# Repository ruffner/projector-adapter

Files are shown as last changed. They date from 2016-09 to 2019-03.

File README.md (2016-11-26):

# projector-adapter

ProjectorAdapter is a solution for timing camera exposure time with a Digital Micromirror Device (DMD) trigger signal for use in 3D recording.

The completed solution, show below, is connected to the projector with the bottom two cables, with the camera trigger cable out the top.
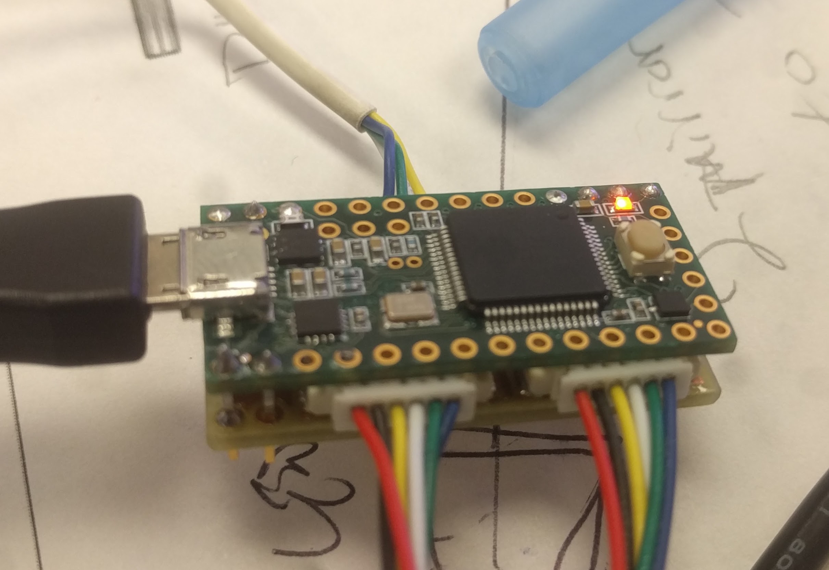
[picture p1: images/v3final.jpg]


### Hardware
The firmware runs on a [Teensy 3.2](https://www.pjrc.com/store/teensy32.html).

A custom made PCB was made with the same footprint as the Teensy3.2 with molex connectors for interfacing with a camera and projector DMD.

The PCB sits below the Teensy, with the 6 pin connectors to and from the projector and the 4 pin header routed to the camera trigger cable.

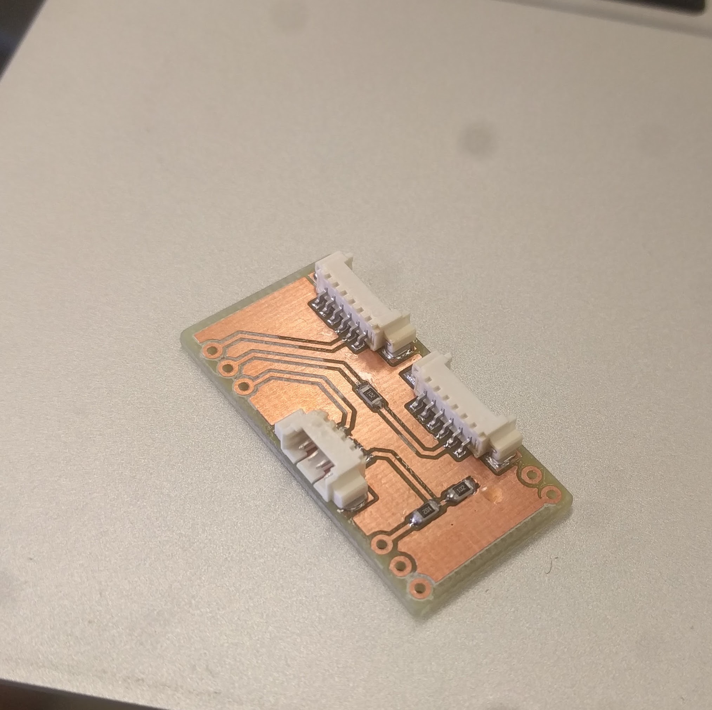
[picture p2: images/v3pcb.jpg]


It is written to interface with Ximea cameras using [this](https://www.ximea.com/support/wiki/apis/XiAPI_Camera_Trigger_and_Synchronization_Signals) protocall.

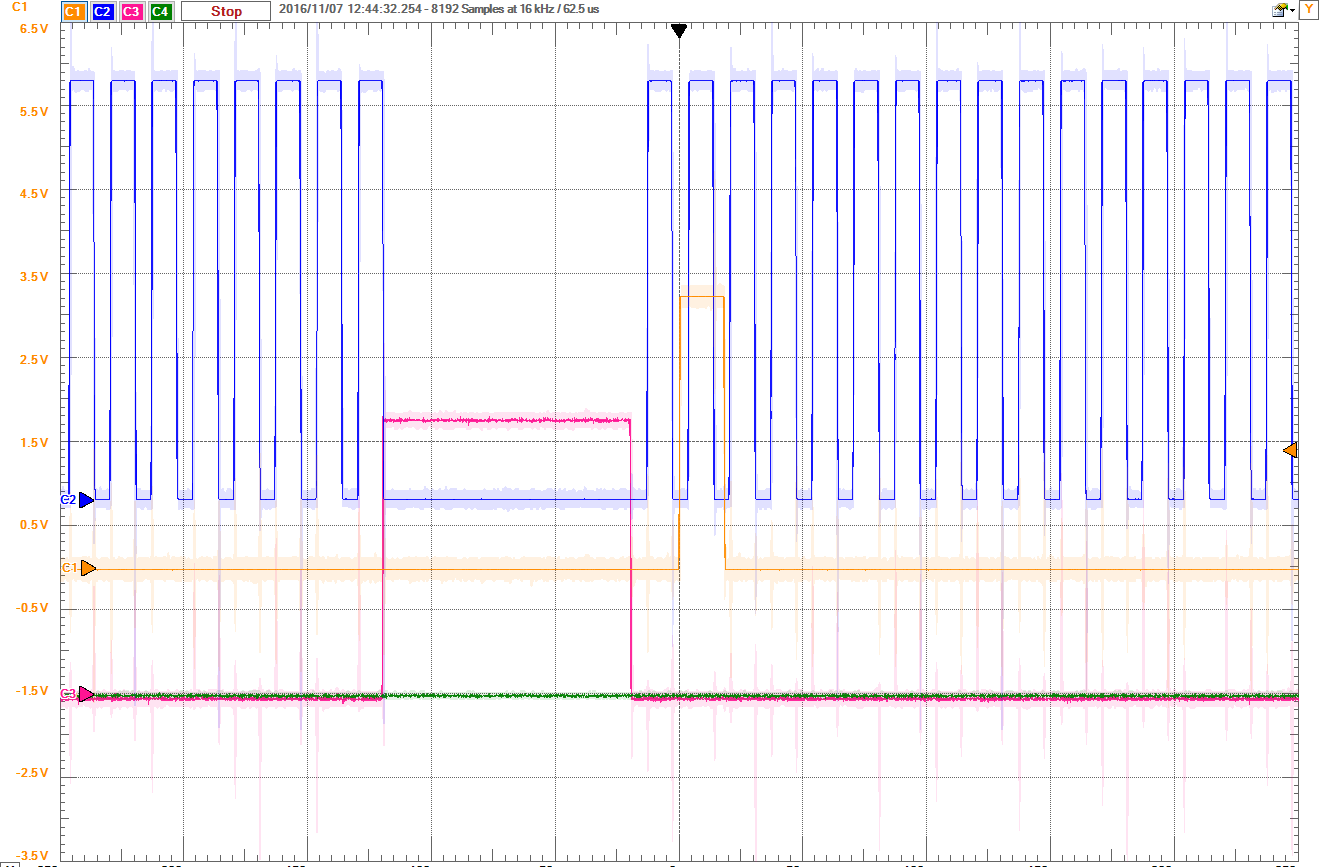
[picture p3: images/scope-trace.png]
Here is a scope trace of the signals involved: 

### Firmware and operation

The pink trace is the trigger output from the Teensy3.2, at 1Hz with a 10% duty cycle. This signal is routed to the projector. Once the projector has been triggered it sends out trigger pulses (blue), intended to trigger the camera. However, it sends pulses until the next rising edge of its 20% duty cycle trigger signal. This would result in the camera exposing more times than desired.

The solution is to intercept the projector output pulses and only pass one through to the camera. The trigger pulse recreated by the Teensy, seen in yellow, must be centered around the pulse it is replicating to avoid skewing of camera exposure timing.

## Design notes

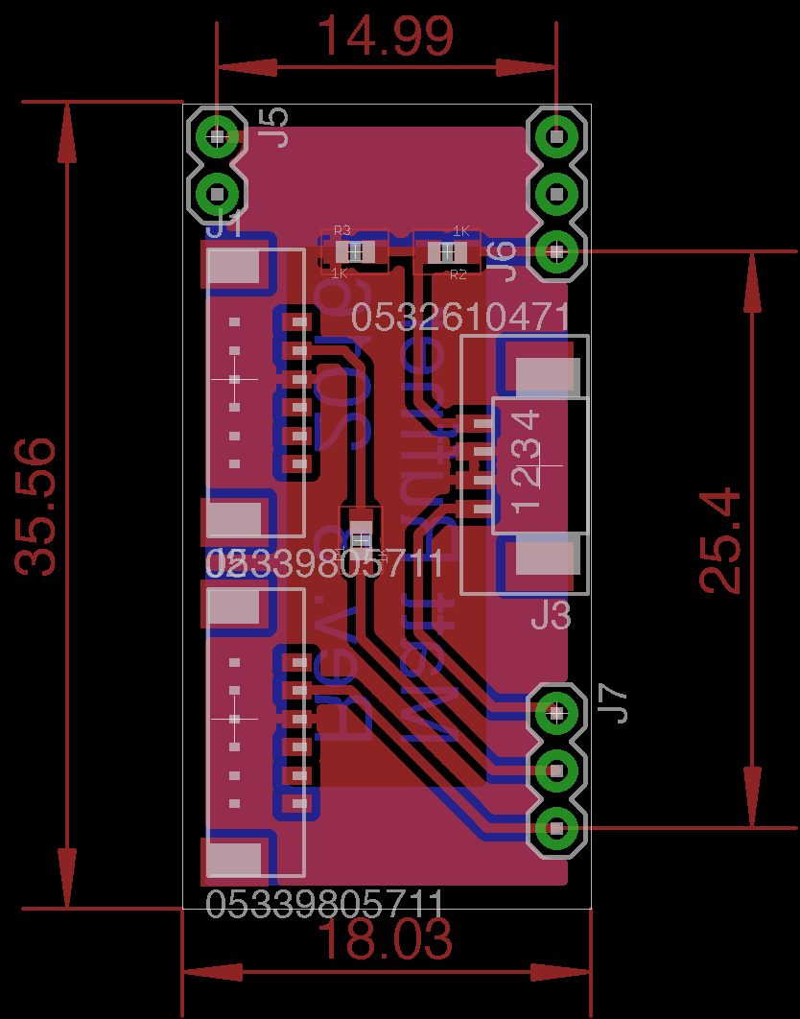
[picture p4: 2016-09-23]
images/rev3board.png

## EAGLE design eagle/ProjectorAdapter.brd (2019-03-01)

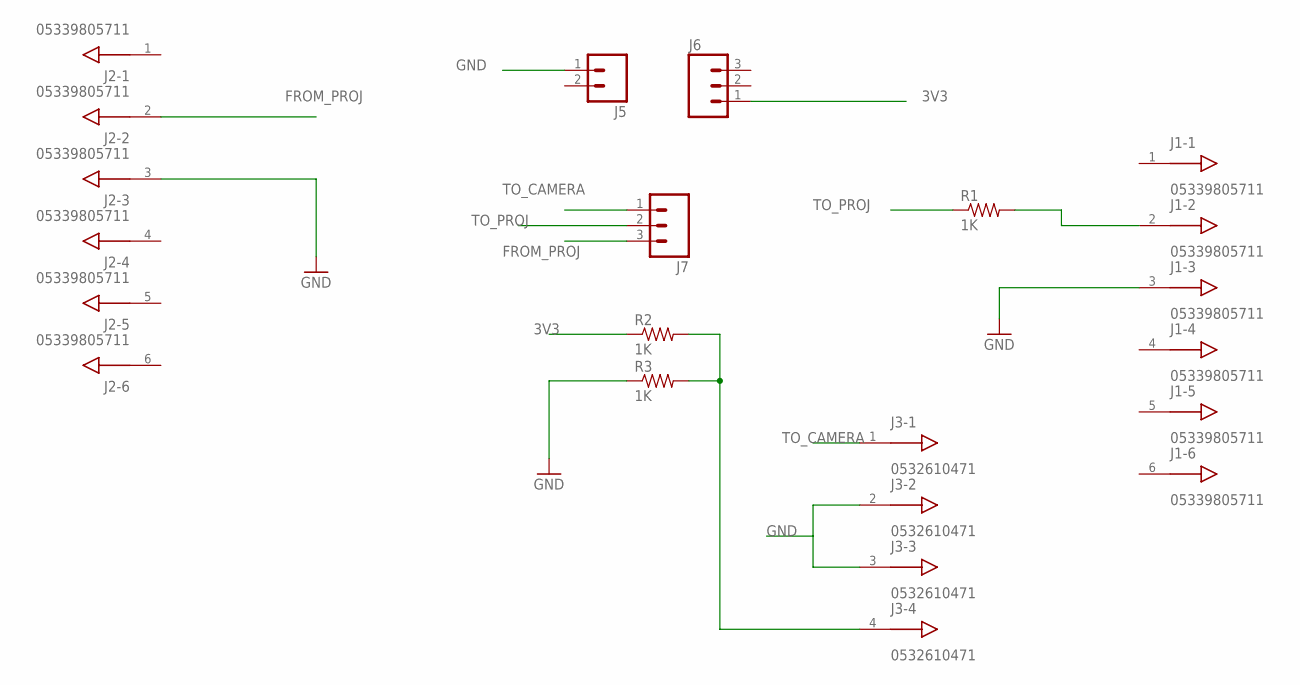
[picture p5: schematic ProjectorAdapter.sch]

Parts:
J1, J2: 05339805711; PICOBLADE53398-0671
J3: 0532610471; PICOBLADE53261-0471
J5: M02PTH; 1X02
J6, J7: M03PTH; 1X03
R1, R2, R3: 1K; 0603-RES

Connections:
3V3: J6.1, R2.1
FROM_PROJ: J2.2, J7.3
GND: J1.3, J2.3, J3.2, J3.3, J5.1, R3.1
unnamed: J3.4, R2.2, R3.2
unnamed: J1.2, R1.2
TO_CAMERA: J3.1, J7.1
TO_PROJ: J7.2, R1.1

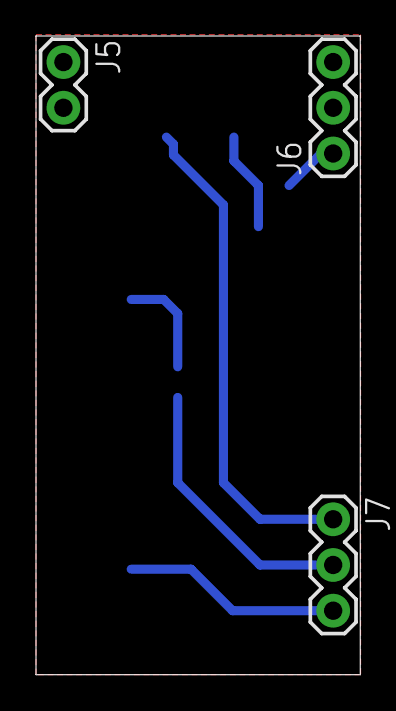
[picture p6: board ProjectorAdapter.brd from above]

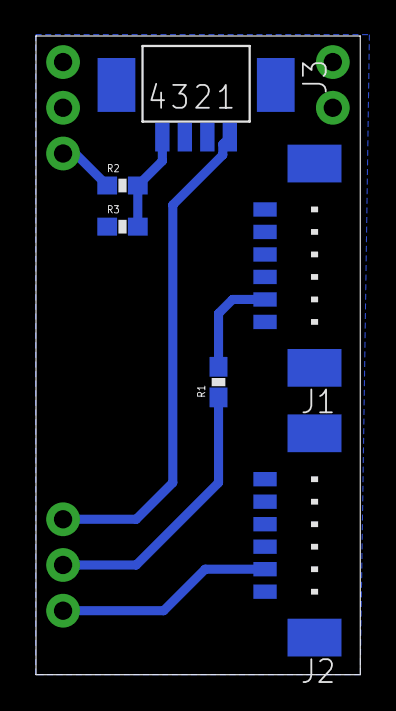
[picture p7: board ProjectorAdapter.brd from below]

Board: 2 copper layers, 18.0 x 35.5 mm, 9 parts (6 on the bottom side), 7 nets.

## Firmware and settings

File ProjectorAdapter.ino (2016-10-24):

// Trigger interface between camera
// and projector
// Matt Ruffner 2016

#include <EEPROM.h>

// pin definitions
#define TO_PROJ   15
#define FROM_PROJ 14
#define TO_CAMERA 16
#define LED       13

#define ID_LEN 11
#define ID_STRING "MR2016v001"

#define TIMEOUT 5000

#define COMMAND_STATUS    '?'
#define COMMAND_CONFIG    'c'
#define COMMAND_RELOAD    'r'
#define COMMAND_SAVE      's'

// not including newline
#define PACKET_SIZE 12

// setting value addresses in EEPROM
#define ADDR_EXP_RATE   12
#define ADDR_EXP_TIME   16
#define ADDR_DUTY_CYCLE 20

unsigned long t_off = 900;  // in ms
unsigned long t_on  = 100;
unsigned long t_exp  = 16;


struct BUFFER {
  unsigned long expRate, expTime, dutyCycle;
};

BUFFER settings;

void setup() {
  Serial.begin(9600);

  // configure i/o
  setupPins();

  // update settings from EEPROM
  readConfigVals();

  generateTimingValues();

  Serial.println("Finished Setup");
  blinkOK();
}

void loop() {
  
  if ( Serial.available() ) handleSerial();

  unsigned long now = millis();

  digitalWrite( TO_PROJ, HIGH );

  while ( !Serial.available() && millis() - now < t_on);
  if (Serial.available()) handleSerial();

  digitalWrite( TO_PROJ, LOW );
  // projector sends back trigger pulses
  // after falling edge

  // timestamp to avoid time out if projector
  // never responds


  // wait until the projector sends the first
  // of the trigger pulses
  //while( !digitalRead( FROM_PROJ ) && millis()-now < t_off );

  now = millis();
  while ( !Serial.available() && millis() - now < t_on && !digitalRead( FROM_PROJ ));
  if (Serial.available()) handleSerial();

  // trigger pulse is wide enough we don't
  // have to worry about it falling before we check here
  if ( digitalRead( FROM_PROJ ) ) {

    // wait till we go low
    while ( digitalRead( FROM_PROJ ) );
    delayMicroseconds(t_exp - 1);

    // pass the pulse on to the camera
    // status blink too
    digitalWrite( TO_CAMERA, HIGH );
    digitalWrite(LED, HIGH);
    delay(t_exp);
    digitalWrite( TO_CAMERA, LOW );
    digitalWrite(LED, LOW);

    // idle and ignore the rest of the pulses
    // from the projector
    //while( millis()-now < t_off );
  }
  while ( millis() - now < t_off );
}

void handleSerial() {
  char c = COMMAND_STATUS;

  c = Serial.read();

  switch ( c ) {
    case COMMAND_STATUS:
      // to populate software fields
      sendConfig();
      blinkOK();
      break;

    case COMMAND_CONFIG:
      if( !parseConfig() )
        blinkError();
      else
        blinkOK();
      break;

    case COMMAND_RELOAD:
      // config stored in EEPROM
      // reset to prior config feature
      readConfigVals();
      blinkOK();
      break;

    case COMMAND_SAVE:
      // save current parameters to EEPROM
      saveConfigVals();
      blinkOK();
      break;
    default:
      blinkError();
  }

  generateTimingValues();

  // flush newline
  if( Serial.peek() == '\n' )
    Serial.read();
}

void generateTimingValues() {
  double t_on_frac = ((double)settings.dutyCycle)/((double)100.0);
  double t_off_frac = 1.0 - t_on_frac;
  
  t_on = (unsigned long)((double)settings.expRate*t_on_frac);
  t_off = (unsigned long)((double)settings.expRate*t_off_frac);
  t_exp = settings.expTime;
}

bool parseConfig() {
  settings.expRate = (unsigned long)Serial.parseInt();
  settings.expTime = (unsigned long)Serial.parseInt();
  settings.dutyCycle = (unsigned long)Serial.parseInt();

  if( settings.expRate != 0 && settings.expTime != 0 && settings.dutyCycle != 0 ){
    saveConfigVals();
    return true;      
  } else {
    return false;
  }
}

bool sendConfig() {
  String buf = String(ID_STRING) + " " + settings.expRate + String(" ") + settings.expTime + String(" ") + settings.dutyCycle;

  Serial.println(buf);

  return true;
}

void readConfigVals() {
  settings.expRate = readLongFromEEPROM(ADDR_EXP_RATE);
  settings.expTime = readLongFromEEPROM(ADDR_EXP_TIME);
  settings.dutyCycle = readLongFromEEPROM(ADDR_DUTY_CYCLE);
}

void saveConfigVals() {
  writeLongToEEPROM( ADDR_EXP_RATE, settings.expRate );
  writeLongToEEPROM( ADDR_EXP_TIME, settings.expTime );
  writeLongToEEPROM( ADDR_DUTY_CYCLE, settings.dutyCycle );
}

unsigned long readLongFromSerial() {
  return (Serial.read() << 24 |
          Serial.read() << 16 |
          Serial.read() << 8 |
          Serial.read());
}

unsigned long readLongFromEEPROM(uint8_t a) {
  return ( EEPROM.read(a) << 24 |
           EEPROM.read(a + 1) << 16 |
           EEPROM.read(a + 2) << 8 |
           EEPROM.read(a + 3) );
}

void writeLongToEEPROM(uint8_t a, unsigned long d) {
  EEPROM.write(a, (uint8_t)(d >> 24));
  EEPROM.write(a + 1, (uint8_t)(d >> 16));
  EEPROM.write(a + 2, (uint8_t)(d >> 8));
  EEPROM.write(a + 3, (uint8_t)(d));
}

void setupPins() {
  // trigger signal to projector
  pinMode( TO_PROJ, OUTPUT );

  // camera trigger signal from projector
  // we debounce this and pass pulse to camera
  pinMode( FROM_PROJ, INPUT );

  // trigger line to camera
  pinMode( TO_CAMERA, OUTPUT );

  // onboard status LED
  pinMode( LED, OUTPUT) ;
}

void blinkOK() {
  digitalWrite(LED, HIGH);
  delay(1000);
  digitalWrite(LED, LOW);
}

void blinkError() {
  for ( int i = 0; i < 5; i++ ) {
    digitalWrite(LED, HIGH);
    delay(150);
    digitalWrite(LED, LOW);
    delay(50);
  }
}

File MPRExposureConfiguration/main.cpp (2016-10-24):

#include <QApplication>
#include "mprexposuredialog.h"


int main(int argc, char *argv[])
{
    QApplication app(argc, argv);
    app.setQuitOnLastWindowClosed(false);
    app.setOrganizationName(QString("Matt Ruffner 2016"));
    app.setOrganizationDomain(QString("github.com/ruffner"));
    app.setApplicationName(QString("Exposure Configuration"));

    MPRExposureDialog w;
    return w.exec();

    return app.exec();
}

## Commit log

2016-09-19 added existing work
    [ProjectorAdapter.brd, ProjectorAdapter.sch]
2016-09-22 updated pcb with molex connectors; created 6 pin connector. updated code for different pin definitions.
    [ProjectorAdapter.brd, ProjectorAdapter.sch]
2016-09-22 made enclosure more shallow
2016-09-23 designed rev3 board to cover full teensy bottom and mount below it.
    [ProjectorAdapter.brd, ProjectorAdapter.sch]
2016-09-27 updated code for v3 pcb
2016-09-29 added v3 PCB image and scope trace.
2016-09-29 added new PCB image
2016-09-29 finally added new pcb image
2016-11-07 updated to recent scope trace. updated readme accordingly
2016-11-26 added pic of v3 pcb in action
2019-03-01 added old silk changes
    [ProjectorAdapter.brd]

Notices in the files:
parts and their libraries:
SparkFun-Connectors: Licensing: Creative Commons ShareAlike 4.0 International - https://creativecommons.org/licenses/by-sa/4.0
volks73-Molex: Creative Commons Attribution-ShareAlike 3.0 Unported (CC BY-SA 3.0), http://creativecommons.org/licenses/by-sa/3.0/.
